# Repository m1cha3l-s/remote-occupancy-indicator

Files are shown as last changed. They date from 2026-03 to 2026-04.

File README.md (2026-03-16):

# Remote occupancy indicator

ESP32 based occupancy marker for meeting rooms, office cubicles and etc. and a simple remote for it. ESP-NOW is used for communication between the the boards, which are using the ESP32-C3 Super Mini

## Assembling
1. Print the both the Indicator and Remote top and bottom parts in a filament of your choice
2. Print the LED part of the Indicator and Remote case in a transparent filament or white filament (not tested) so that the leds can shine through it.
3. Use super glue to put the LED Parts in place (on the inside) if they already don't hold in place, even if they do the super glue wouldn't hurt.
4. The top and bottom of both cases snap together, after you snap them together you can move one the Setup!
5. For mounting use command strips or heavy duty double sided tape!!

## Setup 
1. Select the ESP32 Super Mini in Arduino IDE
2. Flash the MAC-Finder to both the boards and write down the MAC Address which will be sent in the Serial Monitor
3. In the indicator firmware file change the broadcast MAC address to the one the remote gave you
4. Flash!
5. Now in the remote firmware file change the broadcast MAC address to the one the indicator gave you
6. Flash!
7. Now the Indicator and Remote will connect to each other automatically

## Looks
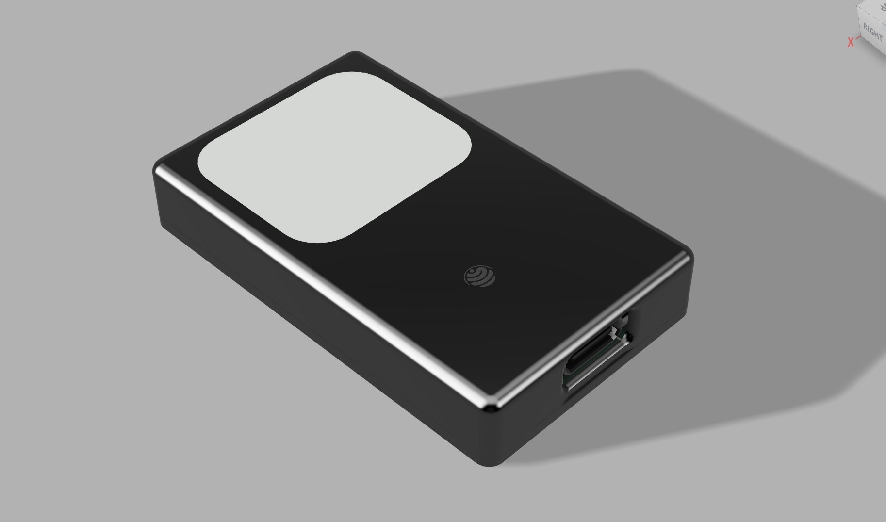
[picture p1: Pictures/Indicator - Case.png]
Indicator case


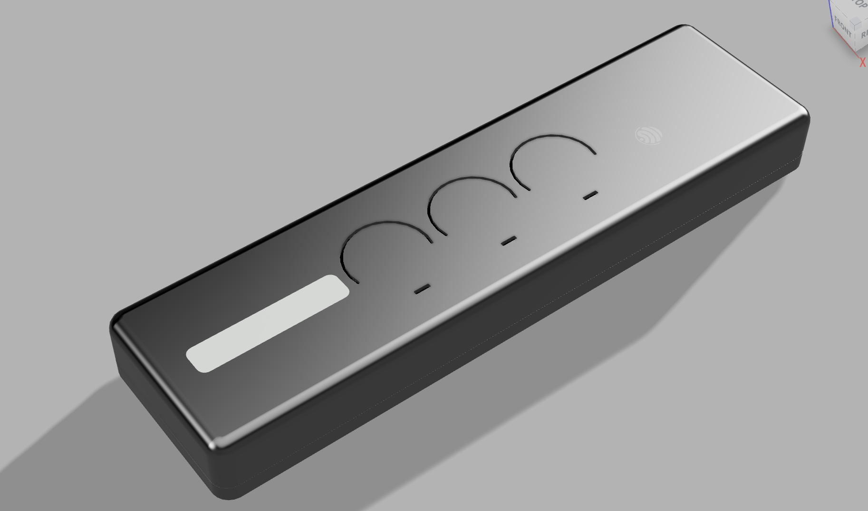
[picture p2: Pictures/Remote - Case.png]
Remote case


## PCB/Schematic
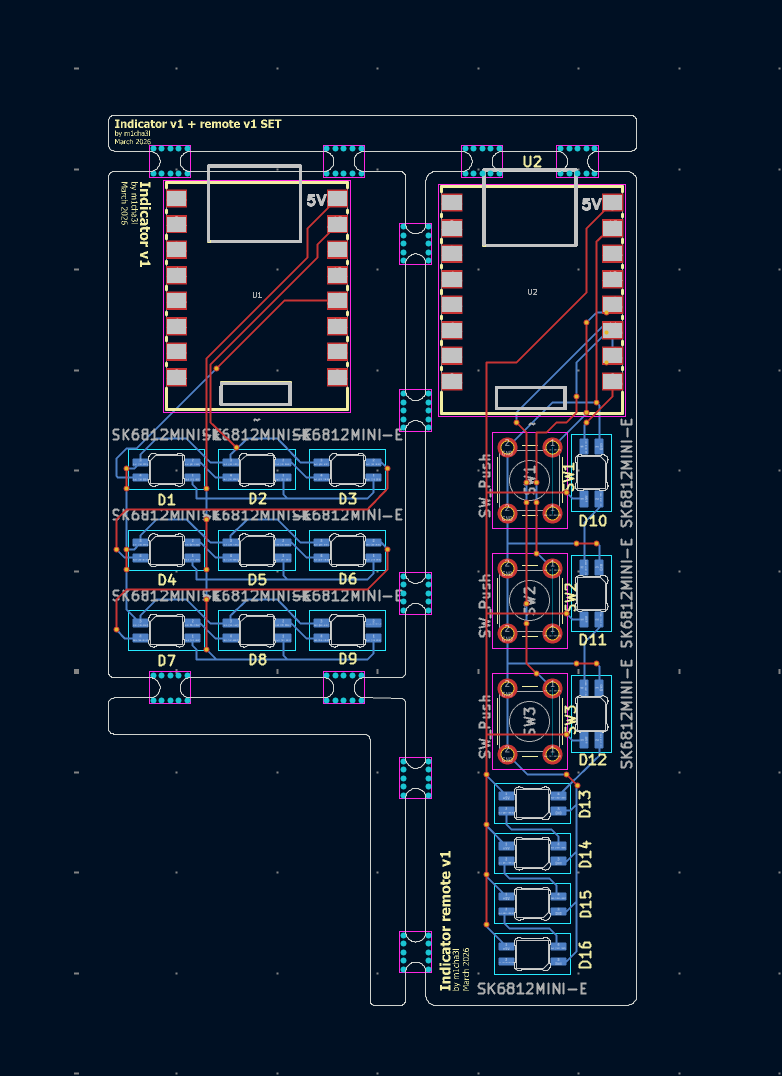
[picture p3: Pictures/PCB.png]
PCB


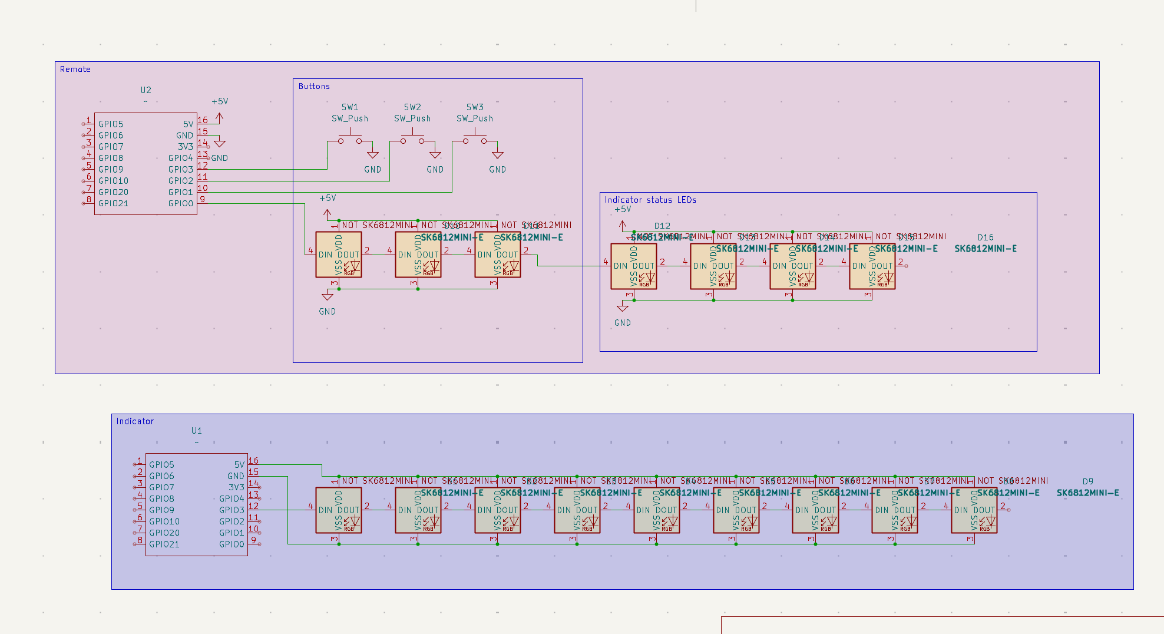
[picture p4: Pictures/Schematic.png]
Schematic


### BOM
| Part Name | Quantity | Price (USD) | Total (USD) | Link |
|---|---|---|---|---|
| ESP32-C3 Super Mini | 2 | 3.16 | 6.32 | https://www.aliexpress.com/item/1005005834458965.html |
| 20pcs SK6812MINI-E | 1 | 1.75 | 1.75 | https://www.aliexpress.com/item/1005008308801366.html |
| 20PCS Tact Push Button Switch 12V Copper 4Pin SMD Micro Switch 6X6X5mm | 1 | 1.62 | 1.62 | 	https://www.aliexpress.com/item/1005005834458965.html |
| Aliexpress shipping | 1 | 2.55 | 2.55 | |
| Custom PCB (with shipping) | 1 | 4.24 | 4.24 | jlcpcb |
| 3D Printed case | 1 | 0 | 0 | none - I have my own printer |
| Total ||| 16.48 |

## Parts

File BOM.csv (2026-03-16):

Name | Cost (USD) | Qty | Total (USD) | Link
3D Printed parts | 0 | 1 | 0 | - | Note: I have a 3D printer so free
PCB | 4.24 | 1 | 4,24 | JLCPCB
20PCS Tact Push Button Switch 12V Copper 4Pin SMD Micro Switch 6X6X5mm | 1.62 | 1 | 1,62 | https://www.aliexpress.com/item/1005005834458965.html
20pcs SK6812MINI-E | 1.96 | 1 | 1,75 | https://www.aliexpress.com/item/1005008308801366.html
ESP32-C3 Super Mini | 3.16 | 2 | 6,32 | https://www.aliexpress.com/item/1005009014269977.html
Aliexpress choice shipping | 2.55 | 1 | 2,55
Total: |  |  | 16,48

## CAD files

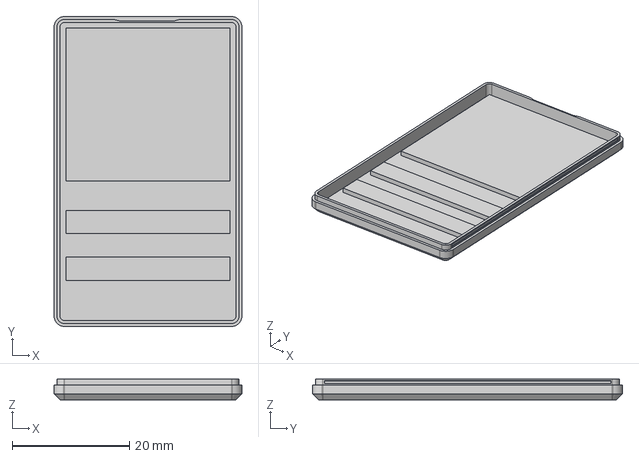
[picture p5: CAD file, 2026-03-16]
Production/Cases/Indicator/Bottom case - Indicator.step
32.0 x 52.8 x 3.50 mm

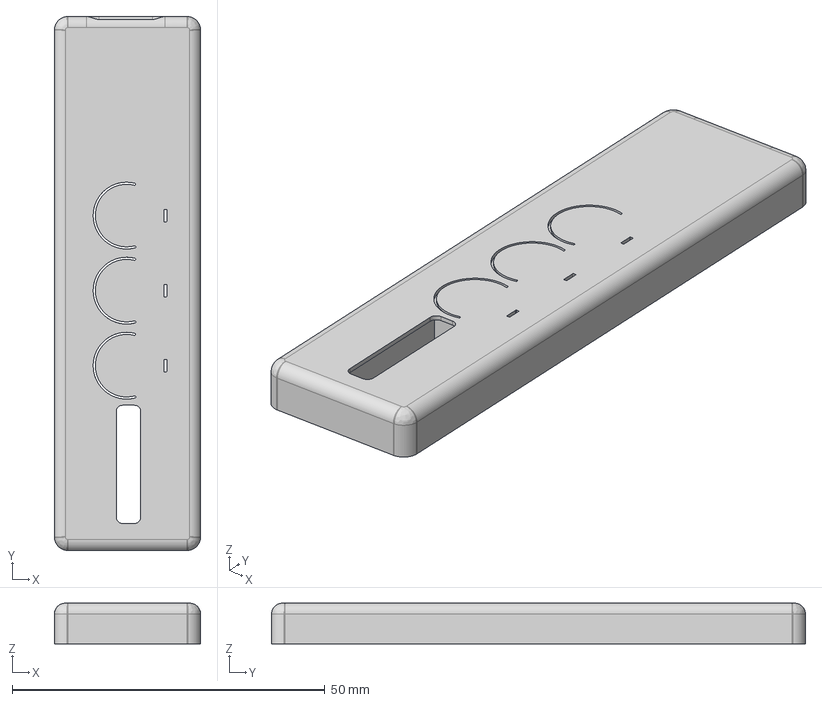
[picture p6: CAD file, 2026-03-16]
Production/Cases/Remote/Top case - Remote.step
23.4 x 85.4 x 6.50 mm

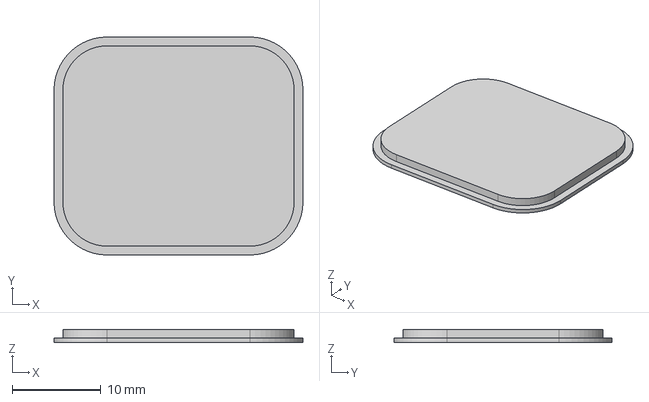
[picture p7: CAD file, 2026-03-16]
Production/Cases/Indicator/LED part.step
28.1 x 24.6 x 1.50 mm

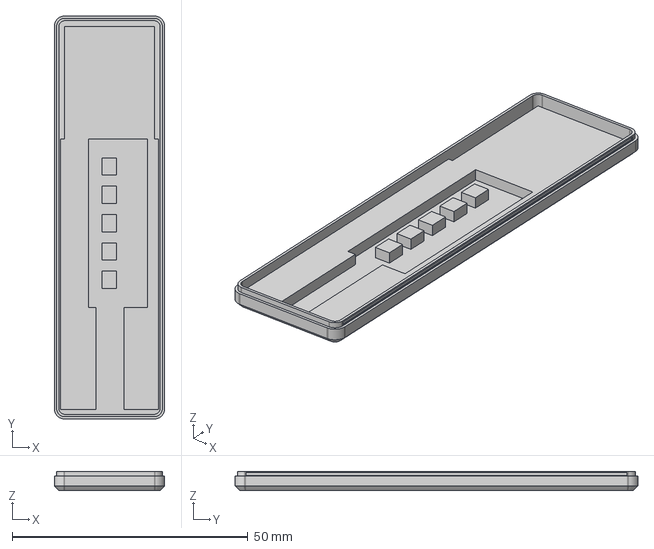
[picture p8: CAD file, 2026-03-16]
Production/Cases/Remote/Bottom case - Remote.step
23.4 x 85.4 x 4.10 mm

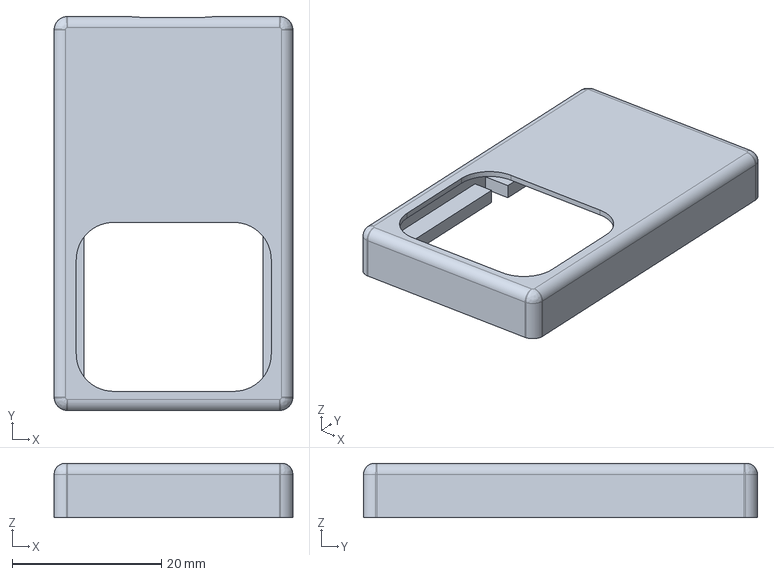
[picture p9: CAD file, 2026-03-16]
Production/Cases/Indicator/Top case - Indicator.step
32.0 x 52.8 x 7.30 mm

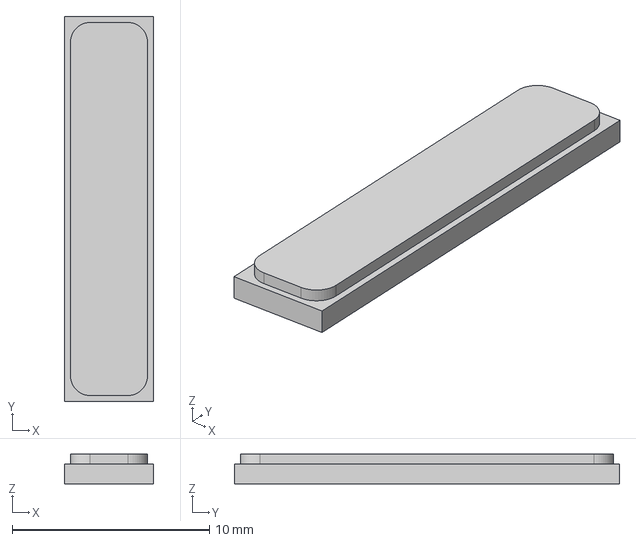
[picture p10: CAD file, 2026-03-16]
Production/Cases/Remote/LED part.step
4.50 x 19.5 x 1.50 mm

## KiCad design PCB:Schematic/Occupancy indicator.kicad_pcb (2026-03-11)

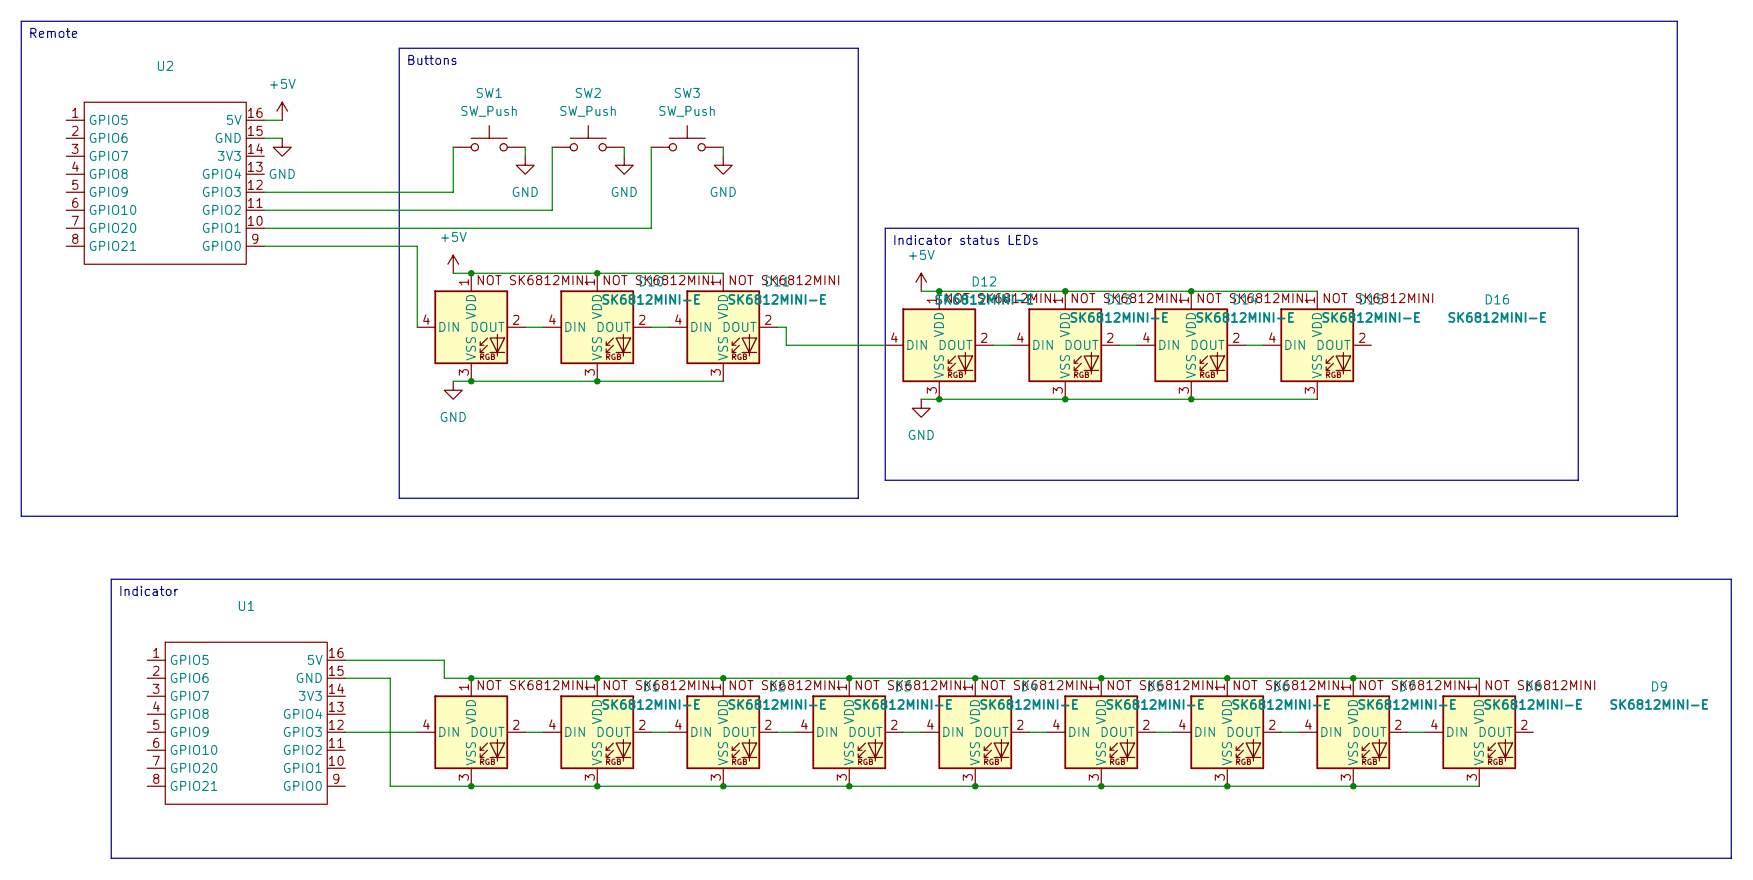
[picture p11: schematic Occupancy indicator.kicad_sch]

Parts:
D1, D2, D3, D4, D5, D6, D7, D8, D9, D10, D11, D12, D13, D14, D15, D16: SK6812MINI-E; SK6812MINI-E_fixed
SW1, SW2, SW3: SW_Push; SW_PUSH_6mm_H5mm
U1, U2: COMM-SMD_16P-L22.5-W18.0-P2.54-TL; Manufacturer Part ESP32C3-SuperMini; LCSC Part Name ESP32C3-SuperMini

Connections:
+5V: D10.1 (VDD), D11.1 (VDD), D12.1 (VDD), D13.1 (VDD), D14.1 (VDD), D15.1 (VDD), D16.1 (VDD), U2.16 (5V)
GND: D10.3 (VSS), D11.3 (VSS), D12.3 (VSS), D13.3 (VSS), D14.3 (VSS), D15.3 (VSS), D16.3 (VSS), SW1.2, SW2.2, SW3.2, U2.15 (GND)
unnamed: D1.4 (DIN), U1.12 (GPIO3)
unnamed: D1.2 (DOUT), D2.4 (DIN)
unnamed: D1.1 (VDD), D2.1 (VDD), D3.1 (VDD), D4.1 (VDD), D5.1 (VDD), D6.1 (VDD), D7.1 (VDD), D8.1 (VDD), D9.1 (VDD), U1.16 (5V)
unnamed: D1.3 (VSS), D2.3 (VSS), D3.3 (VSS), D4.3 (VSS), D5.3 (VSS), D6.3 (VSS), D7.3 (VSS), D8.3 (VSS), D9.3 (VSS), U1.15 (GND)
unnamed: D2.2 (DOUT), D3.4 (DIN)
unnamed: D3.2 (DOUT), D4.4 (DIN)
unnamed: D4.2 (DOUT), D5.4 (DIN)
unnamed: D5.2 (DOUT), D6.4 (DIN)
unnamed: D6.2 (DOUT), D7.4 (DIN)
unnamed: D7.2 (DOUT), D8.4 (DIN)
unnamed: D8.2 (DOUT), D9.4 (DIN)
unnamed: D10.4 (DIN), U2.9 (GPIO0)
unnamed: D10.2 (DOUT), D11.4 (DIN)
unnamed: D11.2 (DOUT), D12.4 (DIN)
unnamed: D12.2 (DOUT), D13.4 (DIN)
unnamed: D13.2 (DOUT), D14.4 (DIN)
unnamed: D14.2 (DOUT), D15.4 (DIN)
unnamed: D15.2 (DOUT), D16.4 (DIN)
unnamed: SW3.1, U2.10 (GPIO1)
unnamed: SW2.1, U2.11 (GPIO2)
unnamed: SW1.1, U2.12 (GPIO3)

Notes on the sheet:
Indicator status LEDs
Indicator
Buttons
Remote

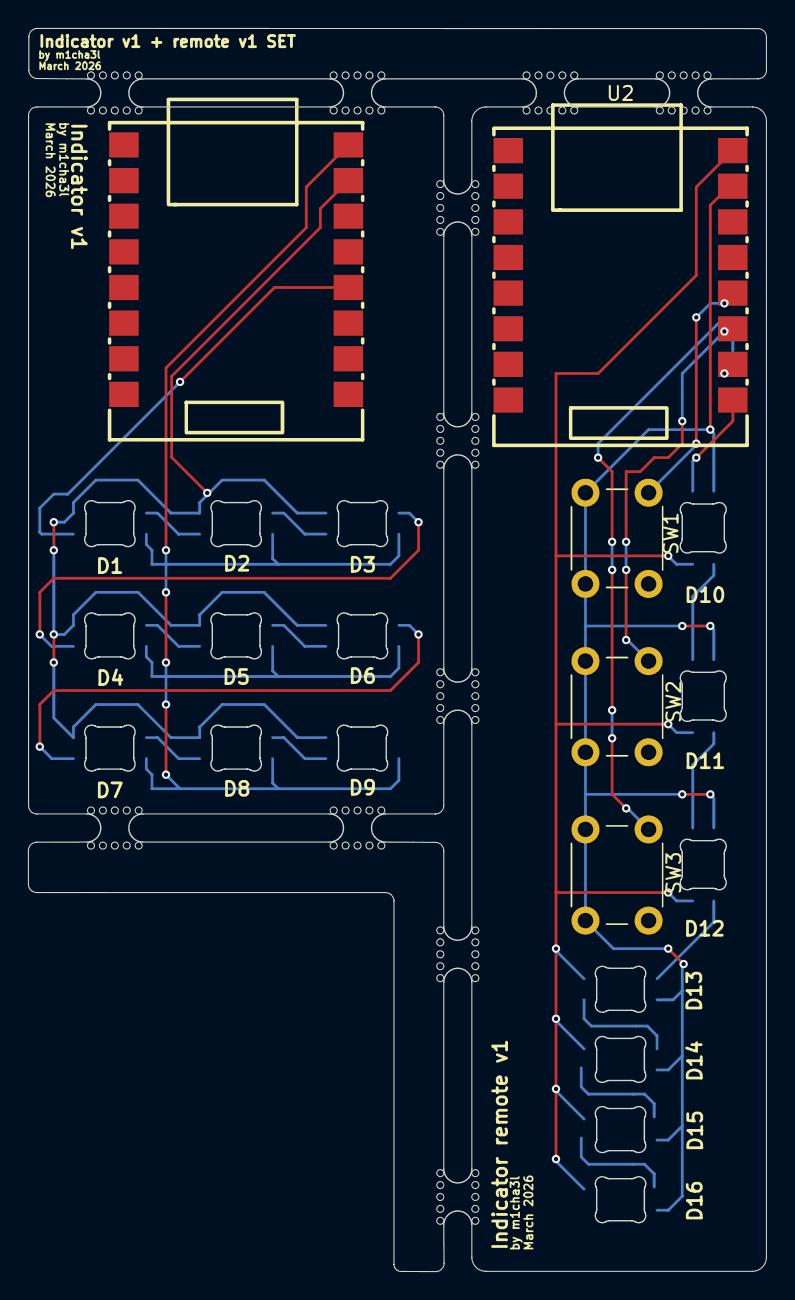
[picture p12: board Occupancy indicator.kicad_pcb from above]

Board: 2 copper layers, 52.6 x 88.6 mm, 21 parts (0 on the bottom side), 23 nets.

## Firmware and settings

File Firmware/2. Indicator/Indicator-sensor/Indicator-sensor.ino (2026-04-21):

#include <WiFi.h>
#include <Wire.h>
#include <esp_now.h>
#include <Adafruit_NeoPixel.h>

  //set pins and number of leds for neopixel
Adafruit_NeoPixel indicator(9, 3, NEO_GRB + NEO_KHZ800);

  //esp-now stuff
uint8_t broadcastAddress[] = {0x1C, 0xDB, 0xD4, 0x44, 0x51, 0x7C};   //MAC Address format 11:22:33:44:55:66 (MAC of your sensor for sending back which color is shown every time it's changed)
#define CHANNEL 0   //channel which esp-now uses

float Sensor_set;
float Indicator_current;

typedef  struct struck_message {
  float set;
  float get;
} struck_message;

struck_message Indicator_data;
struck_message Sensor_data;
esp_now_peer_info_t peerInfo;

void OnDataRecv(const uint8_t *mac, const uint8_t *incomingData, int len) {
  memcpy(&Sensor_data, incomingData, sizeof(Sensor_data));
  Sensor_set = Sensor_data.set;
  Indicator_current = Indicator_data.get;
  Serial.println("Data recv: ");
  Serial.println(Sensor_data.set);
  indicator.fill(Sensor_data.set, 0, 9);
  indicator.show();
  uint32_t currentColor = indicator.getPixelColor(0);
  Indicator_data.get = currentColor;
  esp_err_t result = esp_now_send(broadcastAddress, (uint8_t *) &Indicator_data, sizeof(Indicator_data));
}

void setup() {
  Serial.begin(115200);
  WiFi.mode(WIFI_STA);

  esp_now_init();
  peerInfo.channel = CHANNEL;
  peerInfo.encrypt = false;

  memcpy(peerInfo.peer_addr, broadcastAddress, 6);

  esp_now_add_peer(&peerInfo);
  esp_now_register_recv_cb(esp_now_recv_cb_t(OnDataRecv));

  indicator.begin();
  indicator.fill(0, 0, 9);
  indicator.show();
}

void loop(){}

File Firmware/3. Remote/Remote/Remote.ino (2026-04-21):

#include <WiFi.h>
#include <Wire.h>
#include <esp_now.h>
#include <Adafruit_NeoPixel.h>

Adafruit_NeoPixel remote(7, 0, NEO_GRB + NEO_KHZ800);

  //esp-now stuff
uint8_t broadcastAddress[] = {0xA4, 0xCB, 0x8F, 0x1D, 0x52, 0xB8};   //MAC Address format 11:22:33:44:55:66 (MAC of your remote for sending back which color is shown every time it's changed)
#define CHANNEL 0   //channel which esp-now uses

float Indicator_current;

typedef  struct struck_message {
  float set;
  float get;
} struck_message;

struck_message Indicator_data;
struck_message Remote_data;
esp_now_peer_info_t peerInfo;

void OnDataSent(const uint8_t *mac_addr, esp_now_send_status_t status) {
  Serial.println("Delivering");
}

void OnDataRecv(const uint8_t *mac, const uint8_t *incomingData, int len) {
  memcpy(&Indicator_data, incomingData, sizeof(Indicator_data));
  Indicator_current = Indicator_data.get;
  Serial.println("Data recv: ");
  Serial.println(Indicator_data.get);
  remote.fill(Indicator_data.get, 3, 4);
  remote.show();
}

const int aaa = 3;
const int bbb = 2;
const int ccc = 1;

void setup() {
  Serial.begin(115200);

  pinMode(aaa, INPUT_PULLUP);
  pinMode(bbb, INPUT_PULLUP);
  pinMode(ccc, INPUT_PULLUP);

  WiFi.mode(WIFI_STA);

  esp_now_init();
  peerInfo.channel = CHANNEL;
  peerInfo.encrypt = false;

  memcpy(peerInfo.peer_addr, broadcastAddress, 6);

  esp_now_add_peer(&peerInfo);
  esp_now_register_recv_cb(esp_now_recv_cb_t(OnDataRecv));

  remote.begin();
  remote.fill(0, 3, 4);
  remote.setPixelColor(0, remote.Color(255, 0, 0));
  remote.setPixelColor(1, remote.Color(255, 95, 31));
  remote.setPixelColor(2, remote.Color(0, 255, 0)); 
  remote.show();
}

void loop(){
  if (digitalRead(aaa) == LOW) {
    Remote_data.set = remote.Color(255, 0, 0);
    esp_err_t result = esp_now_send(broadcastAddress, (uint8_t *) &Remote_data, sizeof(Remote_data));
    Serial.println("Button 1");
    delay(1200);
  } 
  else if (digitalRead(bbb) == LOW) {
    Remote_data.set = remote.Color(255, 95, 31);
    esp_err_t result = esp_now_send(broadcastAddress, (uint8_t *) &Remote_data, sizeof(Remote_data));
    Serial.println("Button 2");
    delay(1200);
  }
  else if (digitalRead(ccc) == LOW) {
    Remote_data.set = remote.Color(0, 255, 0);
    esp_err_t result = esp_now_send(broadcastAddress, (uint8_t *) &Remote_data, sizeof(Remote_data));
    Serial.println("Button 3");
    delay(1200);
  }
}

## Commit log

2026-03-11 Added PCB/Schematic and gerber files
    [Occupancy indicator.kicad_pcb, Occupancy indicator.kicad_sch]
2026-03-12 Added MAC_Finder
    First part of the firmware to find MAC Address of the board for ESP-NOW code
2026-03-16 Added Indicator case .f3d file
    Whole case as a assembly
2026-03-16 Added Indicator case parts
    [Bottom case - Indicator.step, LED part.step, Top case - Indicator.step]
2026-03-16 Added Remote case files
    [Bottom case - Remote.step, LED part.step, Top case - Remote.step]
2026-03-16 Added BOM
    [BOM.csv]
